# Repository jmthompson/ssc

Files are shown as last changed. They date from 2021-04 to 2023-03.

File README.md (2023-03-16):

# Simple Serial Card

## Overview

The Simple Serial Card is a low-cost Super Serial Card work-a-like. I designed
this because I needed a way to use ADTPro on my Apple IIe, and the price of
super serial cards on eBay is getting a bit high for my taste.

This card is more or less 100% compatible with the original Apple card. It
uses the same 6551 ACIA mapped to the same I/O locations, and in fact can
use the same firmware ROM.  It does however have some minor differences in the
interest of cost:

1. There are no DIP switches, so you cannot set the default configuration. It
   does, however, include a jumper that can be removed to disable IRQs.
2. Instead of a DB-25 it is wired to use a DB-9 cable like those used by PC
   motherboards.
3. There is no terminal/modem block to change the serial port wiring. Just use
   the appropriate cable instead, or a null modem adapter.

The KiCAD schematics and PCB layout are included. It is a four layer board,
because my fab house of choice charges the same for 2 and 4 layers, so I went
with what made the layout easier.

## Parts List

* A 74LS245 octal bus transceiver (non-TTL appears to have issues with the ROM address decode logic) (U1)
* A 28C256 EEPROM (28-pin JEDEC EPROMs such as the 27128 also work) (U2)
* A 1.8432 MHz 5V oscillator (U3)
* A 22V10 GAL (any speed or variety should work) (U4)
* A W65C51N ACIA (U5)
* Two MAX3232 RS-232 line transceivers (U6, U7)
* Seven 0.1uf ceramic bypass caps (C1-C7)
* Eight 1uf 16V electrolytic caps (C9-C16)
* A 2x5 pin header (J1)
* A 1x2 pin header (J2)

## Assembly

Before assembly you will need to burn firmware ROM into the EEPROM, and burn
the appropriat equations into the GAL. See "Burning the ROM" and "Burning the
GAL" below for more details.

I would suggest socketing all of the chips, but at the very least socket the
ROM and the GAL in case you need to update them.

As mentioned above the header on this card is wired the same as a PC COM
header. There are two varieties of these cables available; this card uses the
newer style which is wired 1:1; that is, pin 1 on the header goes to pin 1
on the DB-9, pin 2 to pin 2, etc. These are sometimes referred to as
"AT/EVEREX" style cables.

There is an asterisk on the card's silkscreen indicating pin one on the RS-232
header; make sure this lines up with pin one on your ribbon cable. Usually this
is the red wire on the ribbon cable.

## Installation

Turn off the computer, put the card in an empty slot, and mount the DB-9 on one
of the small cutouts on the back of the computer (or just run the ribbon cable
through an open cutout if you don't care).

## Design Considerations

Many parts choices were influenced by what I have already in my parts bin, even
if that makes the design non-optimal. For example, I used MAX3232 line drivers
because I have a ton of them. With 12V available on the slots I could've used
different parts and avoided all the charge pump caps, but I didn't feel like
buying more chips.

With the exception of the 22V10 GAL used for glue logic all parts in this design
are still actively available. The GALs are out of production but still readily
available on eBay or Aliexpress (though YMMV as far as quality).

## Burning the ROM

A standard super serial card image should work fine with this card, though
since there are no configuration switches the default settings after power on
or reset will be somewhat random.  Once I have working cards built I will be
creating a customized firmware ROM that sets the defaults to 9600 bps for the
ADT Pro bootstrap.

Since 2K EPROMs are nearly impossible to find I subbed in an AT28C256 EEPROM
(again, I had one already). Only the lower 2K is used by the card, so when
burning you can either duplicate the image 16 times, or fill the upper 30K
with zeroes or some other random data. In theory a AT28C64 EEPROM should also
work (and only waste 6K), but I don't have one to test, and a brief search
suggests they aren't any cheaper than the AT28C256 (presumably because they
are out of production).

I use the TL866 II+ USB programmer along with the minipro Linux client for my
ROM burns.

## Burning the GAL

The equations for the GAL are included as a .pld file for the GALasm program.
If you run Linux or another OS that can run GNU make then you should be able
to just type "make" in the "gal" subfolder to compile the equations into a
.jed file.  Burning this file requires a suitable programmer; I personally
use the same TL866 II+ that I use for burning ROMs, though at least at the time
of this writing the minipro client doesn't know how to burn GALs properly, so
you'll need to use the official client software, either on a Windows PC or
under Wine.

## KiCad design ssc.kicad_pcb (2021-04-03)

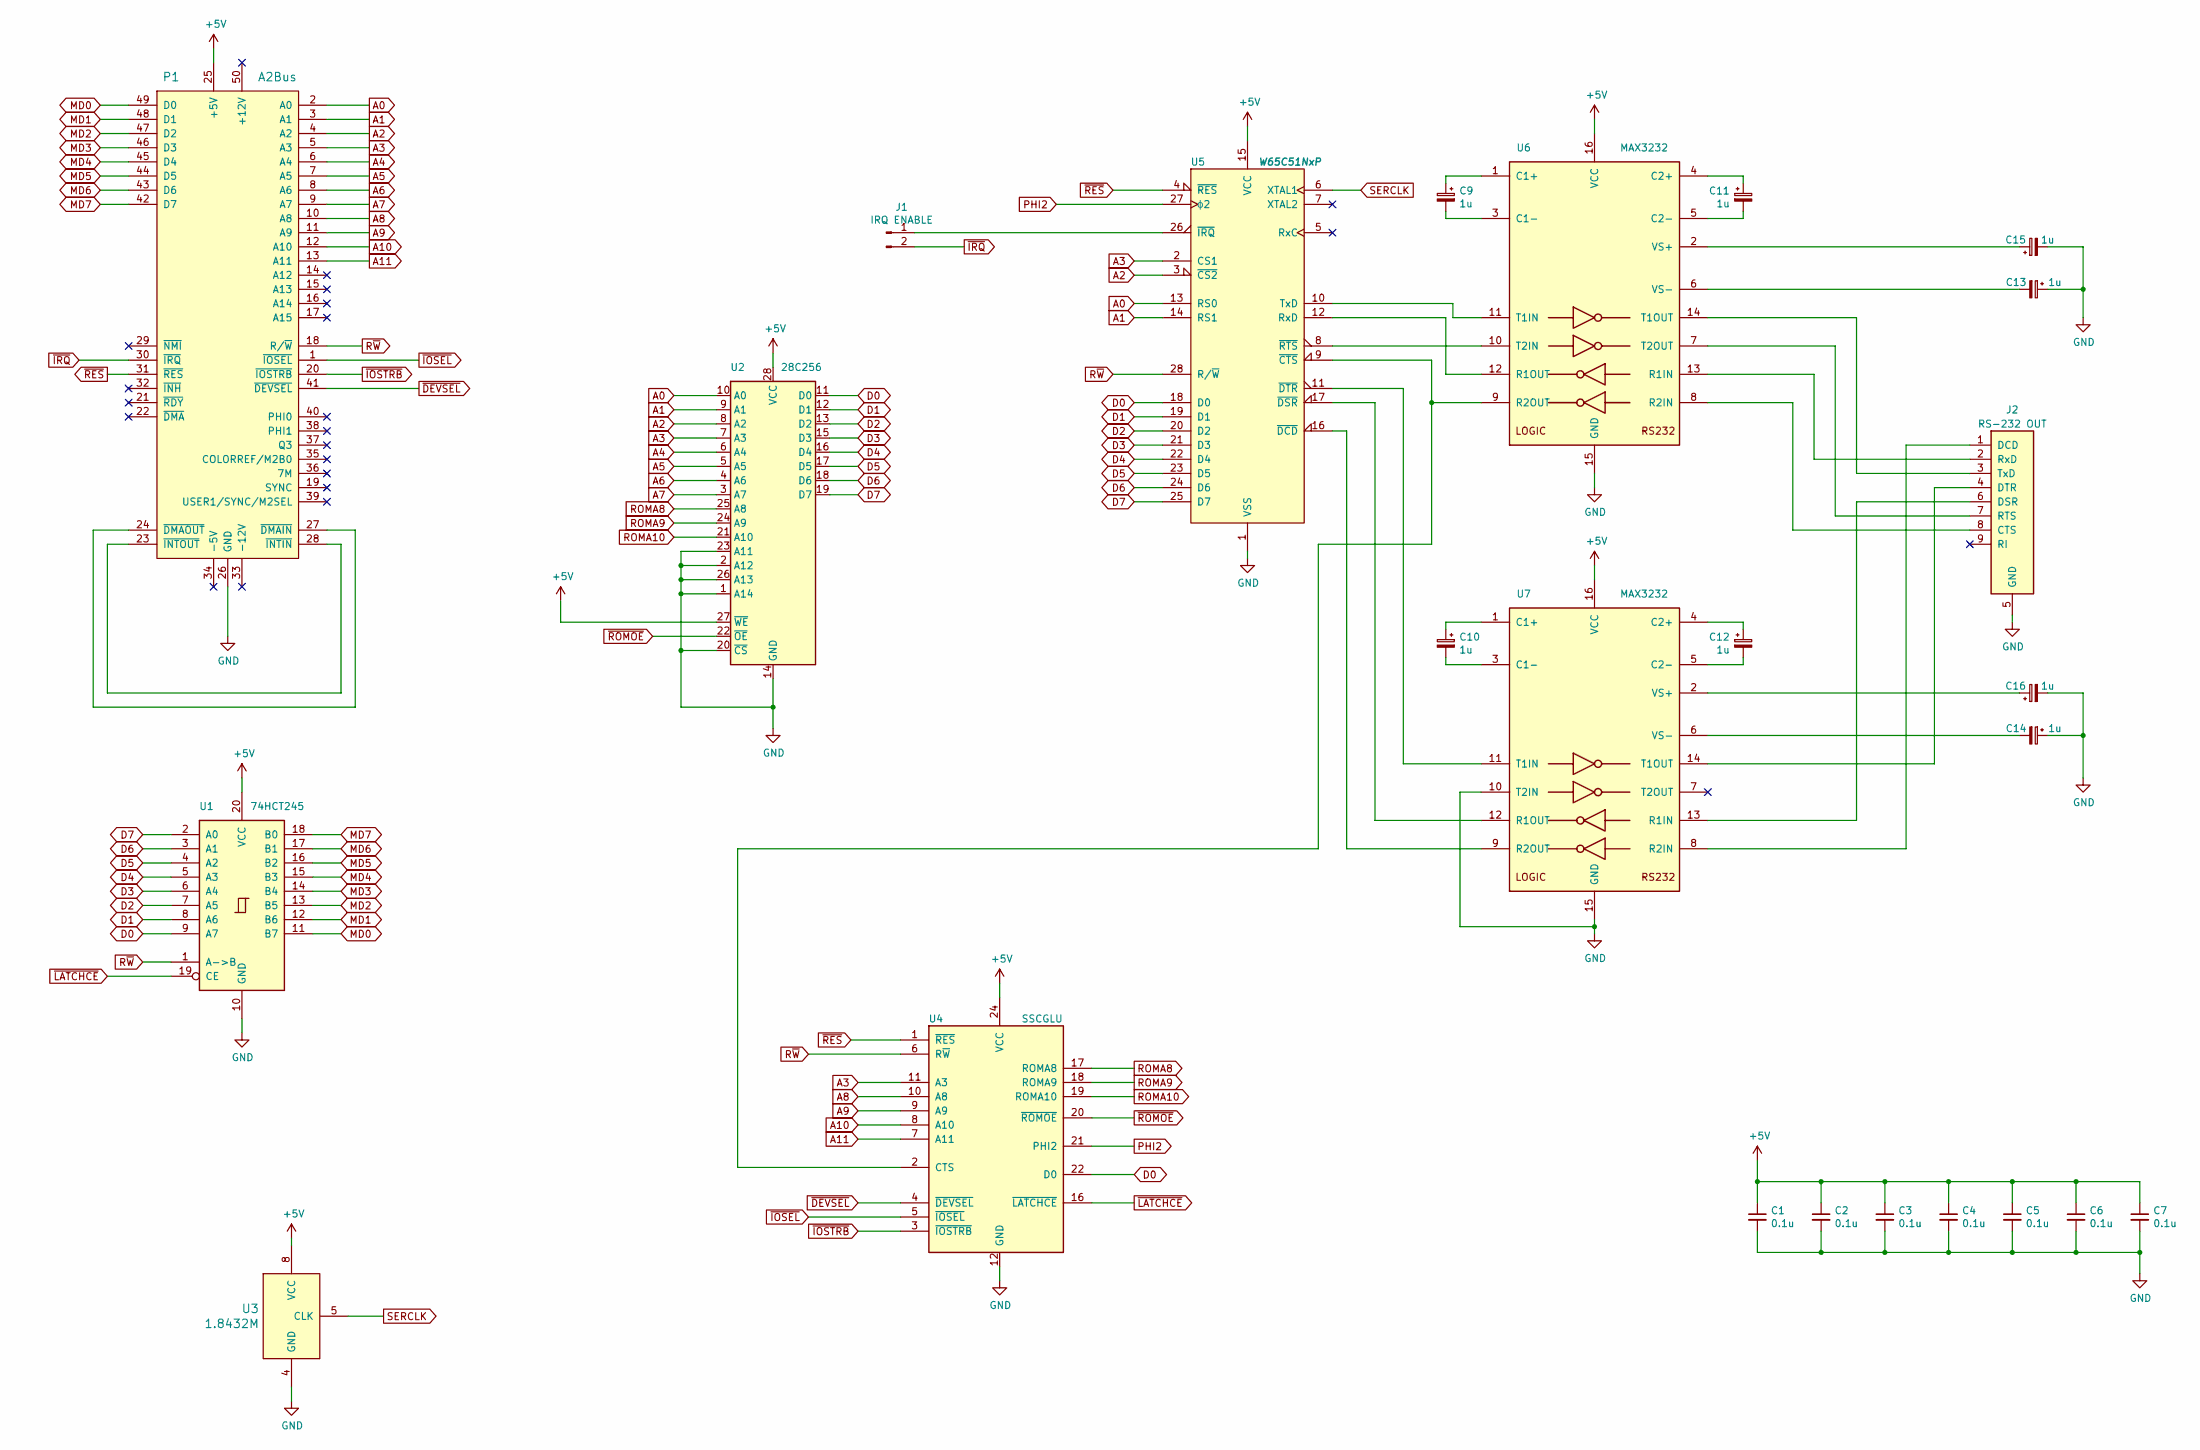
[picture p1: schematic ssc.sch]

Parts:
C1, C2, C3, C4, C5, C6, C7: 0.1u; C_Disc_D4.3mm_W1.9mm_P5.00mm
C9, C10, C11, C12, C13, C14, C15, C16: 1u; CP_Radial_D5.0mm_P2.50mm
J1: IRQ ENABLE; PinHeader_1x02_P2.54mm_Vertical
J2: RS-232 OUT; PinHeader_2x05_P2.54mm_Vertical
P1: A2Bus; Male_Card-Edge_50_pin__100_mil
U1: 74HCT245; DIP-20_W7.62mm_Socket
U2: 28C256; DIP-28_W15.24mm_Socket
U3: 1.8432M; DIP-8_W7.62mm_Socket
U4: SSCGLU; DIP-24_W7.62mm_Socket
U5: W65C51NxP; DIP-28_W15.24mm_Socket
U6, U7: MAX3232; DIP-16_W7.62mm_Socket

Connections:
+5V: C1.1, C2.1, C3.1, C4.1, C5.1, C6.1, C7.1, P1.25 (+5V), U1.20 (VCC), U2.27 (~WE), U2.28 (VCC), U3.8 (VCC), U4.24 (VCC), U5.15 (VCC), U6.16 (VCC), U7.16 (VCC)
A0: P1.2 (A0), U2.10 (A0), U5.13 (RS0)
A1: P1.3 (A1), U2.9 (A1), U5.14 (RS1)
A2: P1.4 (A2), U2.8 (A2), U5.3 (~CS2)
A3: P1.5 (A3), U2.7 (A3), U4.11 (A3), U5.2 (CS1)
A4: P1.6 (A4), U2.6 (A4)
A5: P1.7 (A5), U2.5 (A5)
A6: P1.8 (A6), U2.4 (A6)
A7: P1.9 (A7), U2.3 (A7)
A8: P1.10 (A8), U4.10 (A8)
A9: P1.11 (A9), U4.9 (A9)
A10: P1.12 (A10), U4.8 (A10)
A11: P1.13 (A11), U4.7 (A11)
D0: U1.9 (A7), U2.11 (D0), U4.22 (D0), U5.18 (D0)
D1: U1.8 (A6), U2.12 (D1), U5.19 (D1)
D2: U1.7 (A5), U2.13 (D2), U5.20 (D2)
D3: U1.6 (A4), U2.15 (D3), U5.21 (D3)
D4: U1.5 (A3), U2.16 (D4), U5.22 (D4)
D5: U1.4 (A2), U2.17 (D5), U5.23 (D5)
D6: U1.3 (A1), U2.18 (D6), U5.24 (D6)
D7: U1.2 (A0), U2.19 (D7), U5.25 (D7)
GND: C1.2, C2.2, C3.2, C4.2, C5.2, C6.2, C7.2, C13.1, C14.1, C15.2, C16.2, J2.5 (GND), P1.26 (GND), U1.10 (GND), U2.1 (A14), U2.2 (A12), U2.14 (GND), U2.20 (~CS), U2.23 (A11), U2.26 (A13), U3.4 (GND), U4.12 (GND), U5.1 (VSS), U6.15 (GND), U7.10 (T2IN), U7.15 (GND)
MD0: P1.49 (D0), U1.11 (B7)
MD1: P1.48 (D1), U1.12 (B6)
MD2: P1.47 (D2), U1.13 (B5)
MD3: P1.46 (D3), U1.14 (B4)
MD4: P1.45 (D4), U1.15 (B3)
MD5: P1.44 (D5), U1.16 (B2)
MD6: P1.43 (D6), U1.17 (B1)
MD7: P1.42 (D7), U1.18 (B0)
unnamed: C9.1, U6.1 (C1+)
unnamed: C9.2, U6.3 (C1-)
unnamed: C10.1, U7.1 (C1+)
unnamed: C10.2, U7.3 (C1-)
unnamed: C11.1, U6.4 (C2+)
unnamed: C11.2, U6.5 (C2-)
unnamed: C12.1, U7.4 (C2+)
unnamed: C12.2, U7.5 (C2-)
unnamed: C13.2, U6.6 (VS-)
unnamed: C14.2, U7.6 (VS-)
unnamed: C15.1, U6.2 (VS+)
unnamed: C16.1, U7.2 (VS+)
unnamed: J1.1, U5.26 (~IRQ)
unnamed: J2.1 (DCD), U7.8 (R2IN)
unnamed: J2.2 (RxD), U6.13 (R1IN)
unnamed: J2.3 (TxD), U6.14 (T1OUT)
unnamed: J2.4 (DTR), U7.14 (T1OUT)
unnamed: J2.6 (DSR), U7.13 (R1IN)
unnamed: J2.7 (RTS), U6.7 (T2OUT)
unnamed: J2.8 (CTS), U6.8 (R2IN)
unnamed: P1.23 (~INTOUT), P1.28 (~INTIN)
unnamed: P1.24 (~DMAOUT), P1.27 (~DMAIN)
unnamed: U4.2 (CTS), U5.9 (~CTS), U6.9 (R2OUT)
unnamed: U5.8 (~RTS), U6.10 (T2IN)
unnamed: U5.10 (TxD), U6.11 (T1IN)
unnamed: U5.11 (~DTR), U7.11 (T1IN)
unnamed: U5.12 (RxD), U6.12 (R1OUT)
unnamed: U5.16 (~DCD), U7.9 (R2OUT)
unnamed: U5.17 (~DSR), U7.12 (R1OUT)
PHI2: U4.21 (PHI2), U5.27 (ϕ2)
ROMA8: U2.25 (A8), U4.17 (ROMA8)
ROMA9: U2.24 (A9), U4.18 (ROMA9)
ROMA10: U2.21 (A10), U4.19 (ROMA10)
R~W: P1.18 (R/~W), U1.1 (A->B), U4.6 (R~W), U5.28 (R/~W)
SERCLK: U3.5 (CLK), U5.6 (XTAL1)
~DEVSEL: P1.41 (~DEVSEL), U4.4 (~DEVSEL)
~IOSEL: P1.1 (~IOSEL), U4.5 (~IOSEL)
~IOSTRB: P1.20 (~IOSTRB), U4.3 (~IOSTRB)
~IRQ: J1.2, P1.30 (~IRQ)
~LATCHCE: U1.19 (CE), U4.16 (~LATCHCE)
~RES: P1.31 (~RES), U4.1 (~RES), U5.4 (~RES)
~ROMOE: U2.22 (~OE), U4.20 (~ROMOE)

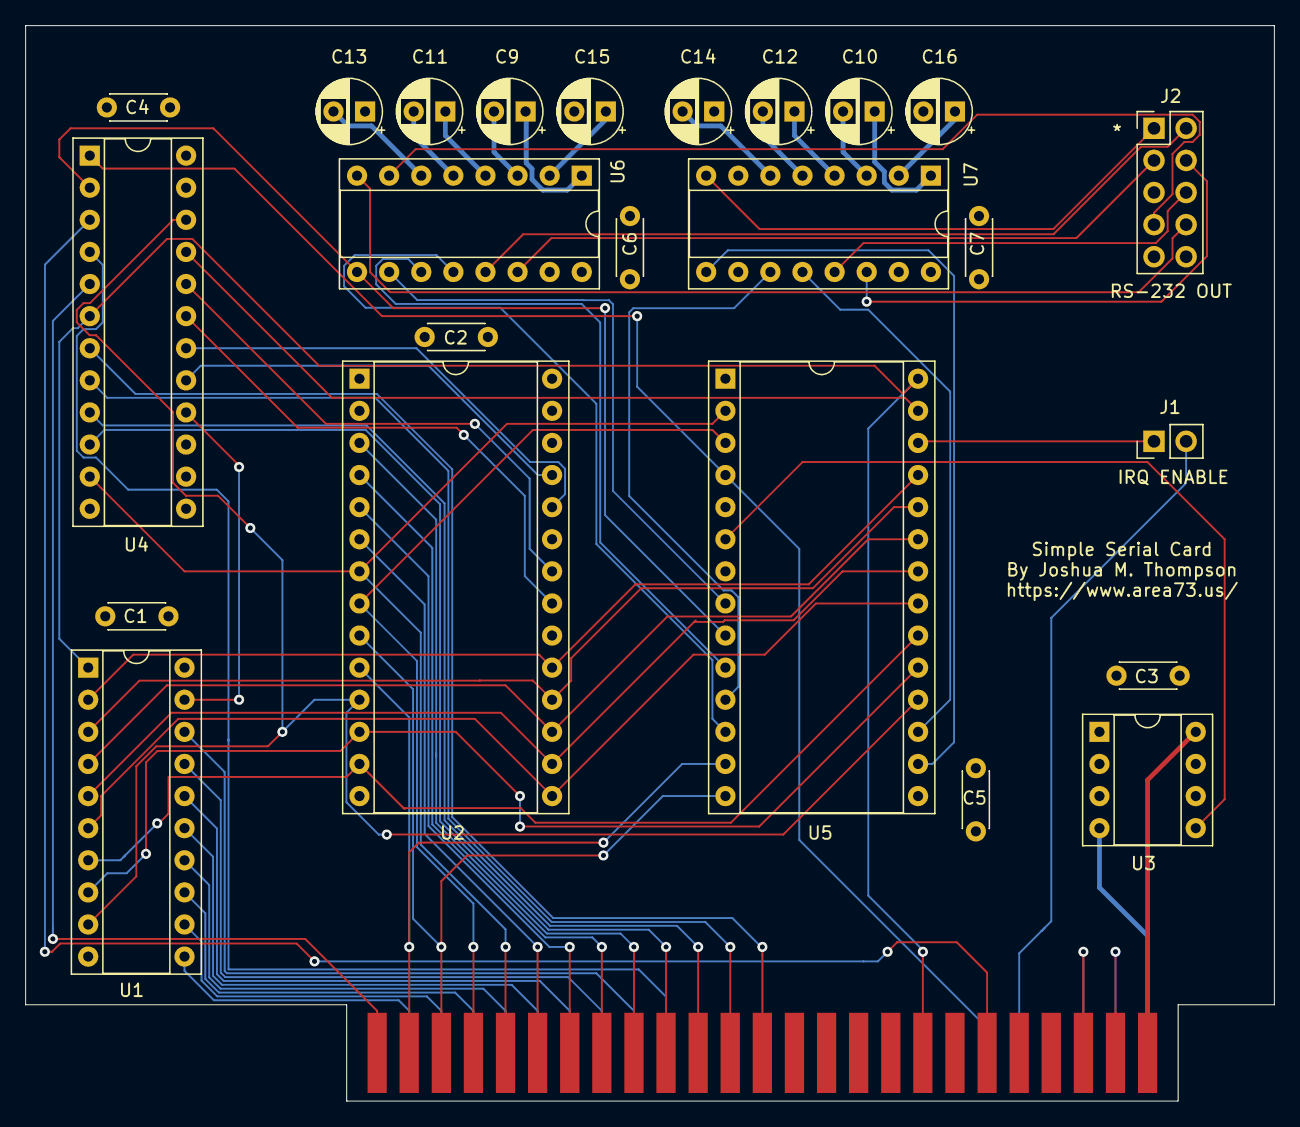
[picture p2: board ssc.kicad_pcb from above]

Board: 4 copper layers, 98.8 x 85.1 mm, 25 parts (0 on the bottom side), 72 nets.

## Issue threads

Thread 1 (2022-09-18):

Hangs when trying to run

StormTrooper, 2022-09-18:
I am having some issues getting this to work.

I've built the circuit and using the same components as per the BOM.
Burnt the gal and ROM (Using  [Apple II Super Serial Card ROM - 341-0065-A.bin - duplicated 16 times)

When I run IN #2 the Apple freezes and I can't type in any further commands.

Is there any troubleshooting steps you can offer. I've  tested all the chips and they work fine so I'm not sure where to start looking next.

jmthompson, 2022-10-09:
I had that same issue, never did diagnose it since my only purpose for the card was to get ADTPro working, and it does not use the firmware. I suspect the issue may be related to the fact that my card omits the DIP switches for configuring the card defaults and it's trying to configure the card into an invalid state as a result.

Unfortunately my Apple IIe isn't set up anymore so I don't thing I'll be doing much with this card anymore. Working ACIAs are too hard to find.

StormTrooper, 2022-10-09:
Thanks for the info. That is unfortunate.  I guess it would either require a hardware mod (dip switches) or hack the original fireware.
Serial cards are horribly expensive now so thought this would be a good alternative.

btb, 2022-11-19:
I tried changing the firmware so it just loads a couple of constant bytes and that didn't help. (see https://forum.vcfed.org/index.php?threads/apple-iie-diy-serial-card.1237266/page-4#post-1285999)

I wonder if it's due to a flaw in the ROM select logic instead?  I notice it depends on RWB which the original card doesn't seem to AFAICT. Do you have any notes for how you came up with the GAL equations?

btb, 2022-11-19:
I see the chip enable for the 74x245 (called "LATCHCE") looks a bit different as well, not taking the latch into account like the Apple SSC does. I think maybe with some new equations this could be made to work.

polpo, 2022-11-28:
@btb thanks for noticing that the select logic seems off. I took a stab at some new equations based directly on the [Apple SSC schematic](https://mirrors.apple2.org.za/Apple%20II%20Documentation%20Project/Interface%20Cards/Serial/Apple%20II%20Super%20Serial%20Card/Schematics/Apple%20II%20Super%20Serial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) but I'm not having much luck. I've replaced the following original equations:

```
C8EN = C8EN * /A8 * /A9 * /A10 * /A11 * /IOSTRB * /RES
     + IOSEL
ROMOE = C8EN * IOSTRB * RWB
      + IOSEL * RWB
LATCHCE = DEVSEL + IOSEL + IOSTRB
```
with:

```
IOLATCH = /IOSEL * IOLATCH + RES + IOSTRB * A8 * A9 * A10
/ROMOE = /IOSEL * /IOSTRB + /IOSEL * IOLATCH
/LATCHCE = /DEVSEL * /ROMOE
```

The above is a simplification of the following logic which more directly follows the schematic. BTW the schematic is fun to follow, as the LS279 SR latches are used as inverters or NAND gates, or as a sort of SR with the roles of S and R flipped.

```
IOLATCH = /(/(/IOSEL * IOLATCH) * /RST * /(IOSTRB * A8 * A9 * A10))
/ROMOE = /IOSEL * /(IOSTRB * /IOLATCH)
```

Hopefully someone who is better at boolean logic or schematic reading than I am can make a better attempt. Or maybe my equations are correct and something is wrong with the board I built.

StormTrooper, 2022-11-28:
I'll give this a test on the 2 boards I built and see what happens.

Glad to hear others are working on this as it would be  a shame to give up on this project

ryucats, 2023-03-07:
Jumping in really late here ...

... it looks like one of the issues is that the GAL isn't mapping the C800 region correctly.  I think this because the monitor shows the correct code at C200 (in my case, SSC in slot 2) but garbage in C800.

Replacing the ROMOE line in the .pld file with:
```
ROMOE = IOSEL
     + IOSTRB
     * /A8 * /A9 * /A10

```
... which is a closer match to the logic as described in the SSC programmer's manual (page 46) makes the correct code show up at C800.

The card still doesn't survive running SlotScan, which may be due to a missing jumper block, but this appears to map the ROMs correctly at least.

ryucats, 2023-03-09:
I think I've got the GAL code nailed down.  I redrew the ROM select logic in KiCAD for clarity, then recreated the logic 1:1 in WinCUPL (as I'm more familiar with that than galasm):

```
Name            Simple Serial Card;
Partno          SSC0001;
Revision        01;
Date            3/9/23;
Designer        Chris RYU;
Company         RyuCats;
Location        None;
Assembly        None;
Device          g22v10;

/* Inputs */

Pin 1 = reset;
Pin 2 = CTS;
Pin 3 = io_C800;
Pin 4 = slot_select;
Pin 5 = io_slot_access;
Pin 6 = RW;
Pin 7 = A11;
Pin 8 = A10;
Pin 9 = A9;
Pin 10 = A8;
Pin 11 = A3;

/* Outputs */

Pin 14 = rom_c800_enable;
Pin 15 = rom_latch;
Pin 16 = ls245_enable;
Pin 17 = eprom_a8;
Pin 18 = eprom_a9;
Pin 19 = eprom_a10;
Pin 20 = rom_enable;
Pin 21 = PHI2;
Pin 22 = d0;

/*  Latch (RS flip-flop) definition:
    Q  = (Q & RESET) # !SET;
*/

PHI2 = !slot_select; /* per schematic */

cf00_access = io_C800 # !A8 # !A9 # !A10; /* CF00 access, pull low */

/*
    if either reset or cf00 access is pulled low, then rom_latch = 1
    if io_slot_access is 0, then rom_latch = 0
    if io_slot_access is 1, then rom_latch = no change
*/
rom_latch = (rom_latch & io_slot_access) # !(reset & cf00_access);
rom_c800_enable = rom_latch # io_C800; /* enable if both pulled low */

ls245_enable = ( io_slot_access & rom_c800_enable & slot_select); /* c800 ? */
rom_enable = (io_slot_access & rom_c800_enable);

eprom_a8 = A8 # !A11;
eprom_a9 = A9 # !A11;
eprom_a10 = A10 # !A11;

d0 = CTS;
d0.OE = RW & !slot_select & !A3;

```

This appears to do the right thing regarding mapping in C800 when Cx00 is accessed, and unmapping again when CF00 is touched.  SlotScan still hangs, but it seems to be happening during the slot probe now, rather than when it tries to switch to 80-column mode with the SSC ROM still sort of mapped in.  I think that's caused by the aforementioned lack of DIP switches, but I'd need to modify the ROM to verify and I'm a bit pressed for time for the next few days.

A .jed file is attached for non-WinCUPL users to test.

[ssc-cr-2023030901.jed.gz](https://github.com/jmthompson/ssc/files/10928252/ssc-cr-2023030901.jed.gz)

polpo, 2023-03-09:
@ryucats - I gave your .jed a try. I just happened to be rewriting and testing out the GAL equations myself after seeing your first comment from a couple days ago, and just now refreshed the page and saw your comment.

Apologies as I'm a big Apple II noob, but here's what I'm doing to verify the GAL: I'm going into the ROM monitor, typing `c200` to latch the c800 enable, then typing `c800` and repeatedly pressing return to start reading the ROM. I'm not reliably seeing the contents of the ROM come out on c800. Sometimes the first few bytes read reliably but then it seems that the latch resets and I start getting `A0` on the monitor. I hooked a scope up to pin 14 of the GAL to see activity on the c800 enable signal, and I do see it briefly going low on successful reads...

As for patching the ROM to hard-code the jumper values, see @btb's comment on the VCFed forums here - he's done the work: https://forum.vcfed.org/index.php?threads/apple-iie-diy-serial-card.1237266/page-4#post-1285999
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
ryucats, 2023-03-09:
Okay, I see what's happening:

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

... as soon as IOSTRB (i.e., access to C800) goes low, that's it for C800 access until it's re-enabled by access to C200.

That's happening because:
```
rom_c800_enable = rom_latch # io_C800; /* enable if both pulled low */
...
rom_enable = (io_slot_access & rom_c800_enable);
```

... which appears to be a byproduct of my equation simplification.   Removing ```# io_C800``` makes the monitor error when C200 is hit.  It's something simple -- but my brain is pretty much tapioca at the moment, so I might need a bit of time to figure out what's supposed to be happening here.

ryucats, 2023-03-09:
It looks like the design is sensitive to data bus timing.  I was using a 74ACT245 for the data bus transceiver ... replacing that with a 74LS245, and no functional changes to the .pld, results in a card that keeps C800 access until CF00 is touched?

@polpo Are you using anything other than a 74LS245 as the data buffer?

polpo, 2023-03-09:
Hmm. I'm using a 74HCT245, as suggested in this project's README. I can dig around and see if I have any LS245s... It's odd that would affect it as it's on the data bus, but I'm willing to entertain anything at this point.

With the GAL equations I've been working on, I could get C800 access to be stable if I repeatedly read from C2xx before reading C800. A single read on C200 isn't enough to reliably set the latch long-term. How finicky...

I was going to experiment with using the GAL22V10's registered outputs and add a couple bodges to latch A8-A10 with PHI0 as a clock to see if it would remove any spurious states on the address bus that look like CFxx.

ryucats, 2023-03-09:
I would take the parts recommendations in the README with a grain of salt -- it seems clear that the original designer didn't ever get the ROM logic working (c.f. the vestigal '365 select logic using A3/D0), so the timing differences between a TTL '245 and a CMOS '245 affecting the C800 ROM portion would not have been noticed.

polpo, 2023-03-14:
@ryucats I didn't have an LS245 in my parts stash so I ordered one and tried it yesterday. What an improvement! Both your .jed and the galasm-based one I've been hacking on work much, much better.

Calling `IN#2` from BASIC still doesn't work quite as expected, but I'm still not 100% confident in my board. For example I can't send commands to change baud rate after typing IN#2, but at least garbage characters appear on the screen when I type on the other end of the serial connection.

StormTrooper, 2023-03-14:
I've also ordered some LS245's and can then run some tests as well on the 2 PCB's I have.

jmthompson, 2023-03-16:
Sorry I'm late to the party. :)

GAL speed is likely part of the issue. My original build was using a 7ns GAL (because I have a lot of them for other projects) and it was way too fast and nothing worked right. It worked much better with a 15ns part; a 25ns GAL would probably be even better but I don't have any that slow.

BTW thanks everyone for fixing this up in my absence. I'm still kinda shocked there is so much interest in something I just thew together to try to get software onto my Apple IIe. I stopped working on this though because I had trouble finding reliable ACIAs, and ended up with an Uthernet II card instead. I occasionally mull over the idea of redesigning this card to use an ACIA built inside of a CPLD, but I don' t have the itch to scratch anymore.

polpo, 2023-03-16:
I keep thinking to myself that I should dive in and emulate an SSC on a Raspberry Pi Pico. I’ve done [ISA card emulation with a Pico](https://github.com/polpo/picogus) so an Apple II card should be possible.

ryucats, 2023-03-17:
@jmthompson When you say that you couldn't find reliable ACIAs, were you talking about NOS NMOS ACIAs, or the currently-available WDC 65C51?

The reason I'm asking is that you are recommending CMOS ACIAs in README.md; the WDC part has a reasonably well-known showstopping transmit bug (discussed at https://forum.6502.org/viewtopic.php?f=4&t=2543 ) that makes those parts essentially worthless for most applications, and NOS CMOS 65C51s are IME always defective.  NMOS, on the other hand, seems to be okay -- does that match with your experience?

jmthompson, 2023-03-18:
@ryucats yeah I am aware of the WDC bug, though I had completely forgotten about it until after I made the schematics and boards. In this case I'm talking about my poor luck at finding the NMOS parts on eBay that actually worked reliably. I had one whole batch, for example, that just returned $FF no matter what byte was received, and wouldn't transmit at all. That's why I mentioned the idea of recreating the ACIA in a CPLD (or maybe a Raspberry Pi Pico plus some level shifters).

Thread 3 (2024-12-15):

Too many DRC errors from KicAD 8.0

vitasam, 2024-12-15:
Hi, was trying to open the project in KiCAD 8.0, the DRC reports way too many errors and warnings:
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

Is it something to be ignored (before ordering the PCB board)?

jmthompson, 2024-12-16:
I wouldn't trust it; when it was originally done (way back in KiCad 5.0 I think) it had 0 errors; my guess is something got messed up with the upgrade while it was trying to bring over custom footprints.

Also FWIW the design is not 100% stable; I had a lot of problems trying to get it to work and gave up. Been meaning to redesign this with different parts but never got around to it; maybe while I'm currently unemployed I'll take a stab at it.

vitasam, 2024-12-17:
Hi, thank you for the info!
From my experience the DRC in KiCAD 8.0 is a kind of trustable, so maybe it makes sense to spend time and migrate project in to a new KiCAD.

By the way, JLCPCB takes from $2 for 1-2 layers PCB 100x100 mm, and the same price for 4 layers PCB 50 x 50 mm. I wonder does it make sense to redesign the PCB for 2 layers?

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
